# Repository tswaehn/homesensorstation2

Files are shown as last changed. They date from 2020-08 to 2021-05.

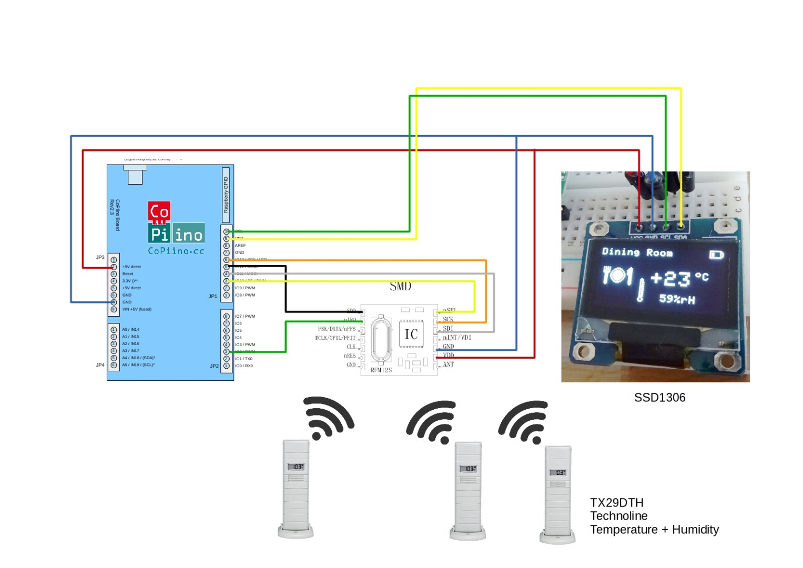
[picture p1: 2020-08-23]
dok/Home Sensor Station I - wiring.jpg

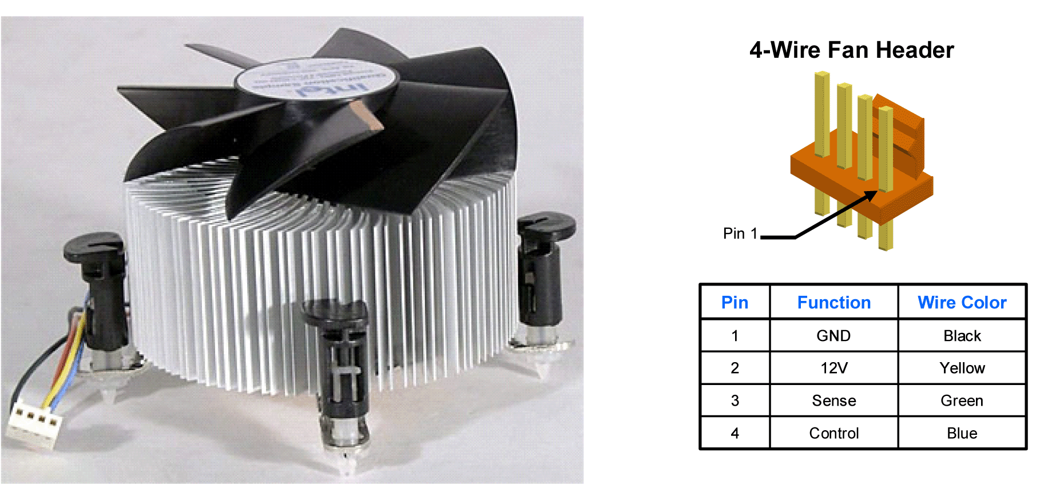
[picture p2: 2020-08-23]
dok/4pin_fan_connector_C0203-Figure1.gif

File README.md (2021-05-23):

# homesensorstation2

## requirements
*  NodeMCU Board
   * Arduino compatible ESP8266 controller board (4MB flash, I2C, SPI, WiFi, ... )
   * doc in german https://www.mikrocontroller-elektronik.de/nodemcu-esp8266-tutorial-wlan-board-arduino-ide/
*  RFM12B
   * https://www.ebay.de/itm/RFM12B-868Mhz-Wireless-Transceiver-from-HopeRF-RFM12B-868S2P-/171670876052
*  HomeSensor2 Base board
   * this board hosts the RFM12B, SSD1306 display and NodeMCU
   * schematics is in the repo 
*  SSD1306 display (128x64 pixels)
   * any compatible display with I2C will do
*  Sensors must be TX29 compatible
   * see here http://fredboboss.free.fr/articles/tx29.php
*  Arduino IDE 1.8.9
   * I personally prefer exactly this version, others may do it as well

## installation
*  install ESP8266 boards (follow instructions https://github.com/esp8266/Arduino)
*  load the arduino project
*  select "Tools" - "Board" - "NodeMCU (ESP 12E Module)" 
*  select "Tools" - "Port" 
*  run compile button in Arduino
*  upload to NodeMCU
*  done

***ATTENTION !!!!***

* use ardino IDE version 1.8.5
* use ESP library https://arduino.esp8266.com/stable/package_esp8266com_index.json
* use EPS board version 2.7.4
* use settings:
   * arduino_esp_settings.png

## pin-out
*  SSD1306 Display 
   * SDA: D2
   * SCL: D1
*  RFM12B
   * MOSI: D7
   * MISO: D6
   * SCK: D5
   * SS: D8
   * IRQ: D0

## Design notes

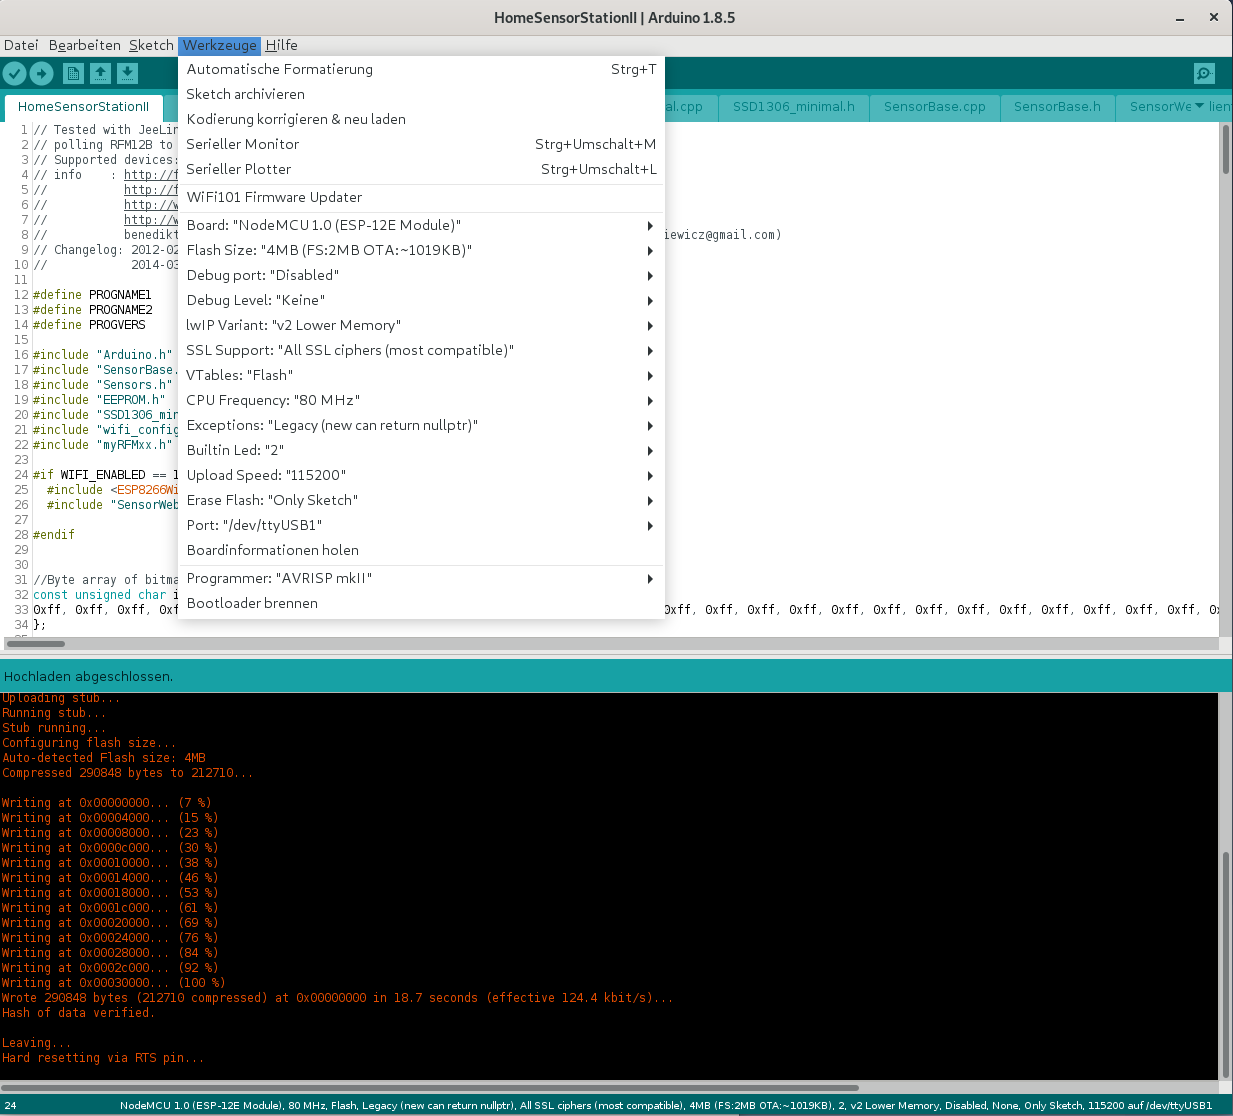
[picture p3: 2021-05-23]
arduino_esp_settings.png

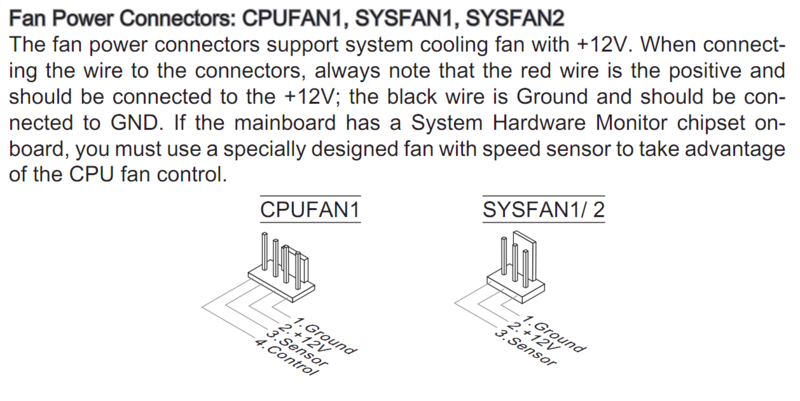
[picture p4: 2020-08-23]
dok/3pin and 4pin fan connecotr.png

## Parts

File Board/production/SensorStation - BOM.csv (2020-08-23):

Part | Value | Device | Package | Description
C1 | 100uF/10V | CPOL-EUE2.5-6 | E2,5-6 | POLARIZED CAPACITOR, European symbol
C2 | 200uF/25V | CPOL-EUE2.5-6 | E2,5-6 | POLARIZED CAPACITOR, European symbol
C3 | 100nF/10V | C-EU025-025X050 | C025-025X050 | CAPACITOR, European symbol
C4 | 100n/25V | C-EU025-025X050 | C025-025X050 | CAPACITOR, European symbol
D1 | 1N4148DO35-10 | 1N4148DO35-10 | DO35-10 | DIODE
DISP1 | DISPLAY-OLED-128X64NO-HOLES | DISPLAY-OLED-128X64NO-HOLES | DISPLAY-OLED-128X64-NO-HOLES | 128x64 Dot Matrix OLED Module
DISP2 | DISPLAY-OLED-128X32 | DISPLAY-OLED-128X32 | DISPLAY-OLED-128X32 | 128x32 Dot Matrix OLED Module with I2C interface based on SSD1306 chip
DISP3 | DISPLAY-OLED-128X64-I2CNO-HOLES | DISPLAY-OLED-128X64-I2CNO-HOLES | DISPLAY-OLED-128X64-I2C-NO-HOLES | OLED 0.96 128x64 I2C Display"
H1 | MOUNT-HOLE3.2 | MOUNT-HOLE3.2 | 3,2 | MOUNTING HOLE with drill center marker
H2 | MOUNT-HOLE3.2 | MOUNT-HOLE3.2 | 3,2 | MOUNTING HOLE with drill center marker
H3 | MOUNT-HOLE3.2 | MOUNT-HOLE3.2 | 3,2 | MOUNTING HOLE with drill center marker
H4 | MOUNT-HOLE3.2 | MOUNT-HOLE3.2 | 3,2 | MOUNTING HOLE with drill center marker
IC1 | ESP12E_DEVKITNO-HOLES | ESP12E_DEVKITNO-HOLES | ESP12E_DEVKIT-NO-HOLES | ESP12E DEVKIT BOARD
IC2 | RFM12B/69CW | RFM12B/69CW | RFM12B/69CW
IC3 | 7805TV | 7805TV | TO220V | Positive VOLTAGE REGULATOR
JP1 |  | PINHD-1X1 | 1X01 | PIN HEADER
JP2 | FAN_OUTPUT | PINHD-1X4 | 1X04 | PIN HEADER
JP3 | FAN_PWR_INPUT | PINHD-1X2 | 1X02 | PIN HEADER
JP4 |  | PINHD-1X1 | 1X01 | PIN HEADER
Q1 | IRF510 | IRF510 | TO220 | N-Channel Enhancement MOSFET (HEXFET); 100V; 5,6A; 0,54Ohm
R1 | 4k7 | R-EU_0204/5 | 0204/5 | RESISTOR, European symbol
R2 | 4k7 | R-EU_0204/5 | 0204/5 | RESISTOR, European symbol
R3 | 4k7 | R-EU_0204/5 | 0204/5 | RESISTOR, European symbol
R4 | 4k7 | R-EU_0204/5 | 0204/5 | RESISTOR, European symbol
SJ1 |  | SJ2W | SJ_2 | SMD solder JUMPER
SJ2 |  | SJ2W | SJ_2 | SMD solder JUMPER
SJ3 |  | SJ2W | SJ_2 | SMD solder JUMPER
SJ4 |  | SJ2W | SJ_2 | SMD solder JUMPER

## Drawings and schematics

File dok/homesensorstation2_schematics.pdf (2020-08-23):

## sven.ginka@gmail.com sven.ginka@gmail.com

This schematic is open source. Use only when sharing alike revisions publically.

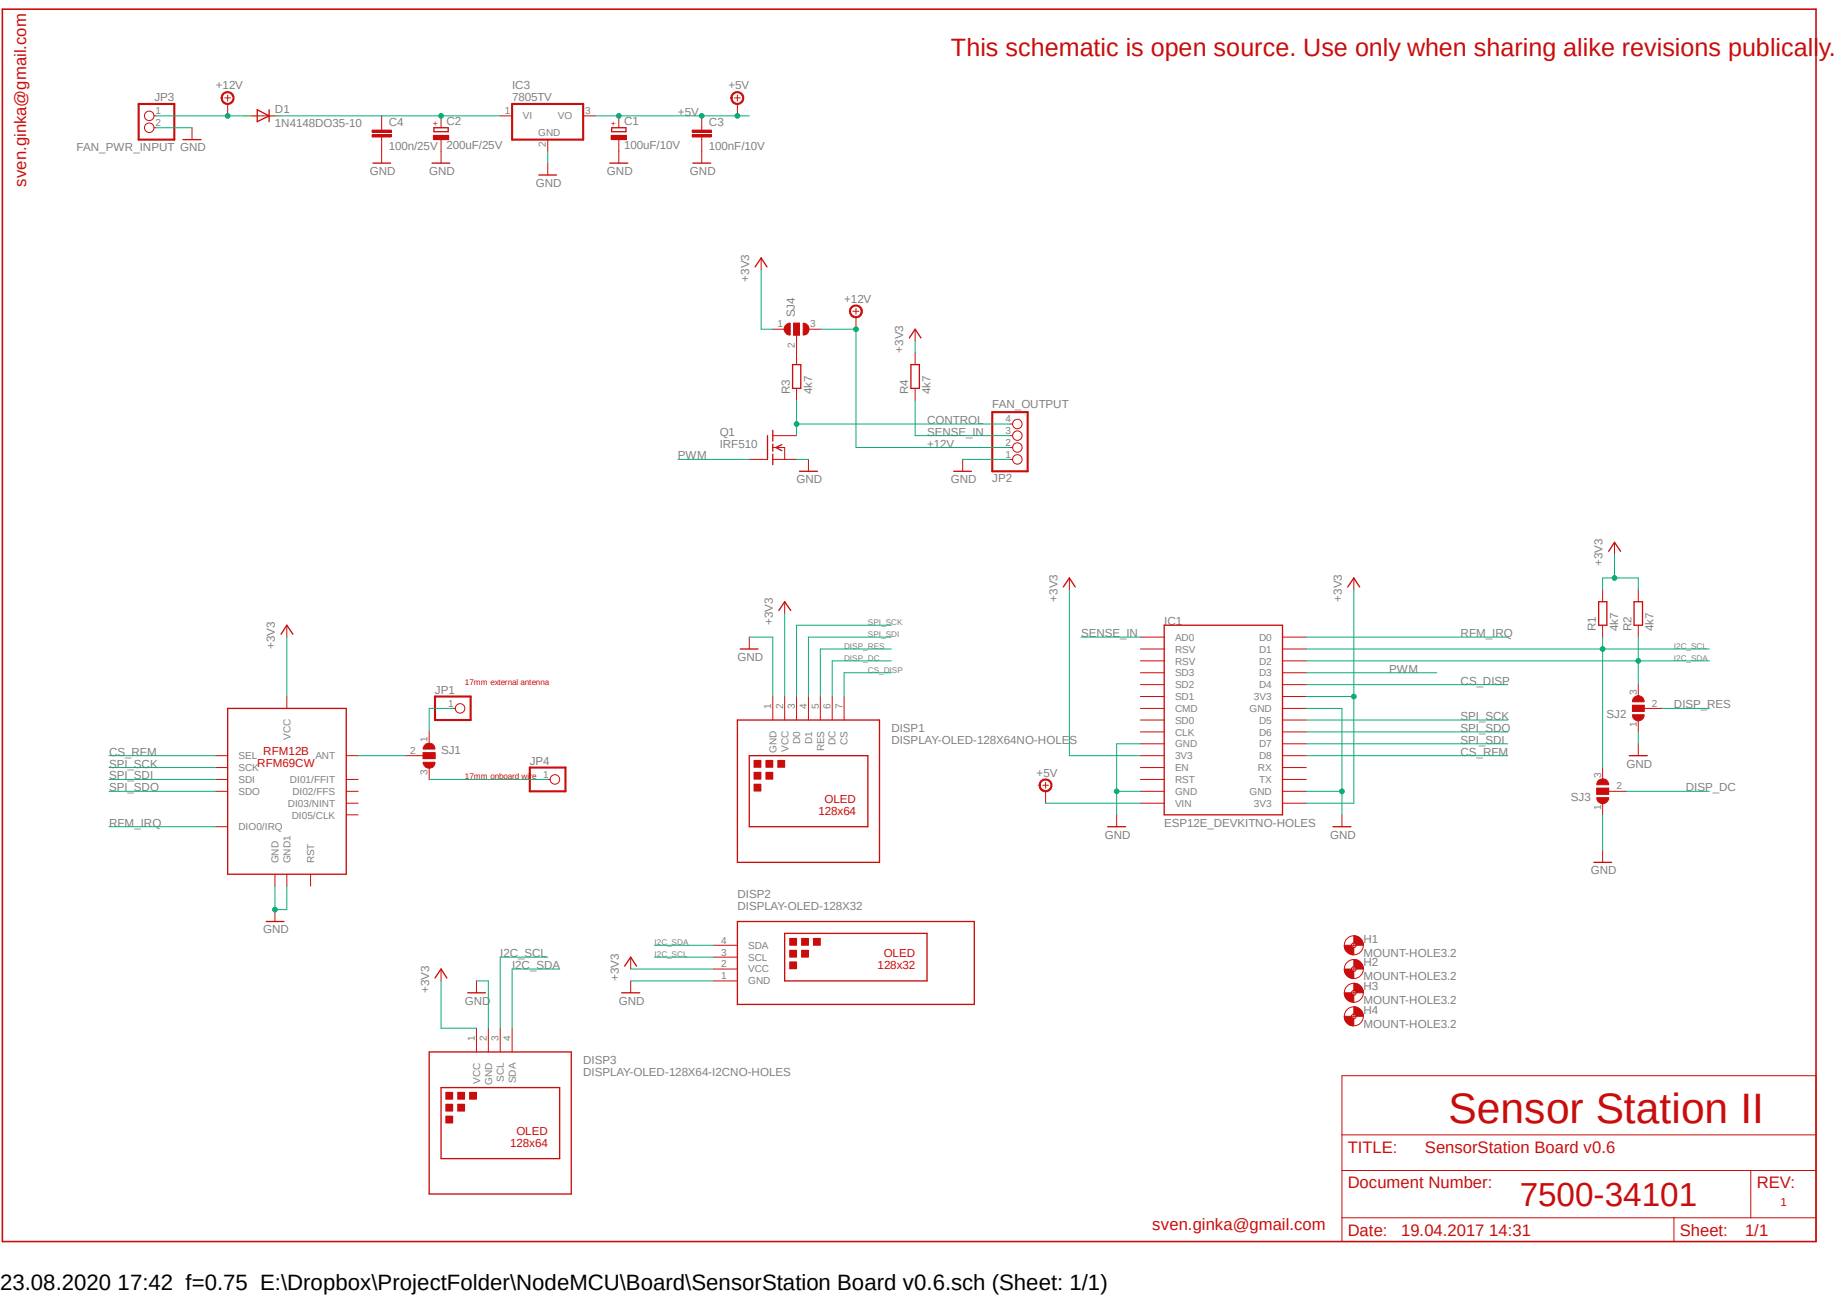
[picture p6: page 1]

DISPLAY-OLED-128X64-I2CNO-HOLES ⁺³V³

Document Number: 7500-34101 | REV: 1

Date: 19.04.2017 14:31 | Sheet: 1/1

23.08.2020 17:42 f=0.75 E:\Dropbox\ProjectFolder\NodeMCU\Board\SensorStation Board v0.6.sch (Sheet: 1/1)

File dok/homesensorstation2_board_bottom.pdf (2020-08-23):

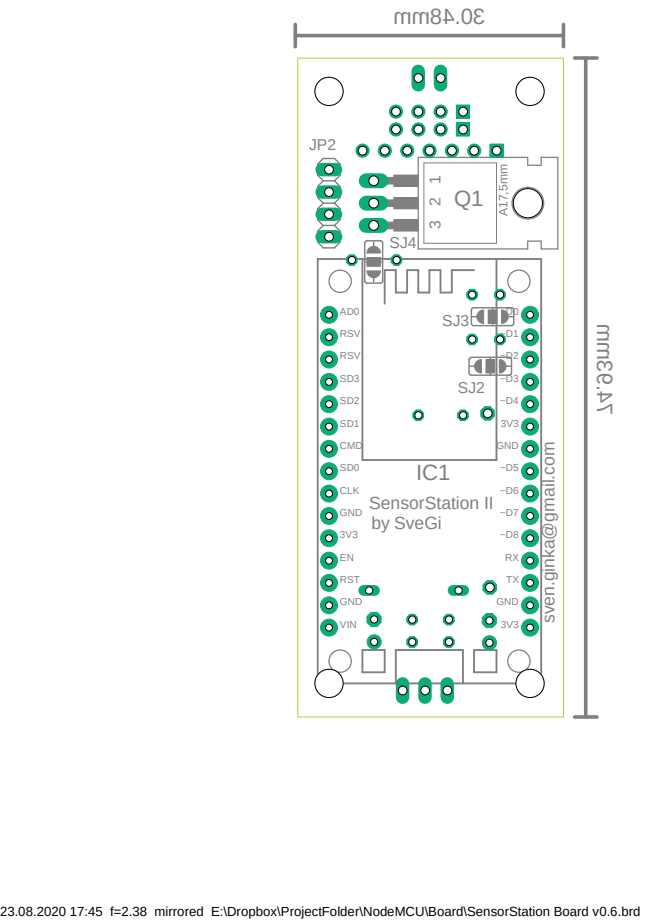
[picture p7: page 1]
RSV; CMD; CLK; GND; RST; VIN; SensorStation II; by SveGi; sven.ginka@gmail.com IC1

23.08.2020 17:45 f=2.38 mirrored E:\Dropbox\ProjectFolder\NodeMCU\Board\SensorStation Board v0.6.brd A¹⁷,5mm

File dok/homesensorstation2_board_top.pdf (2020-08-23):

- | + by CoPiino Electronics | HomeSensorStationII rev1 SJ1

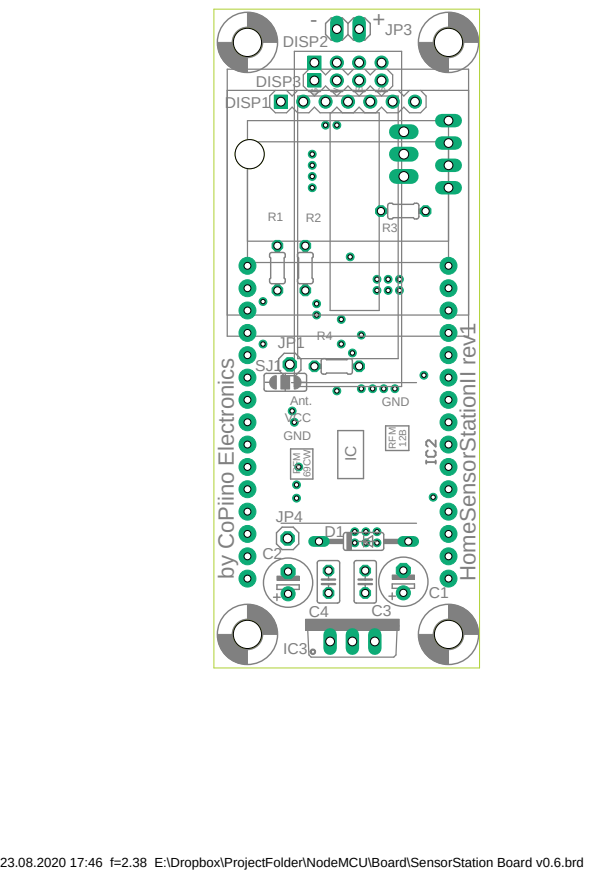
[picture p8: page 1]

23.08.2020 17:46 f=2.38 E:\Dropbox\ProjectFolder\NodeMCU\Board\SensorStation Board v0.6.brd

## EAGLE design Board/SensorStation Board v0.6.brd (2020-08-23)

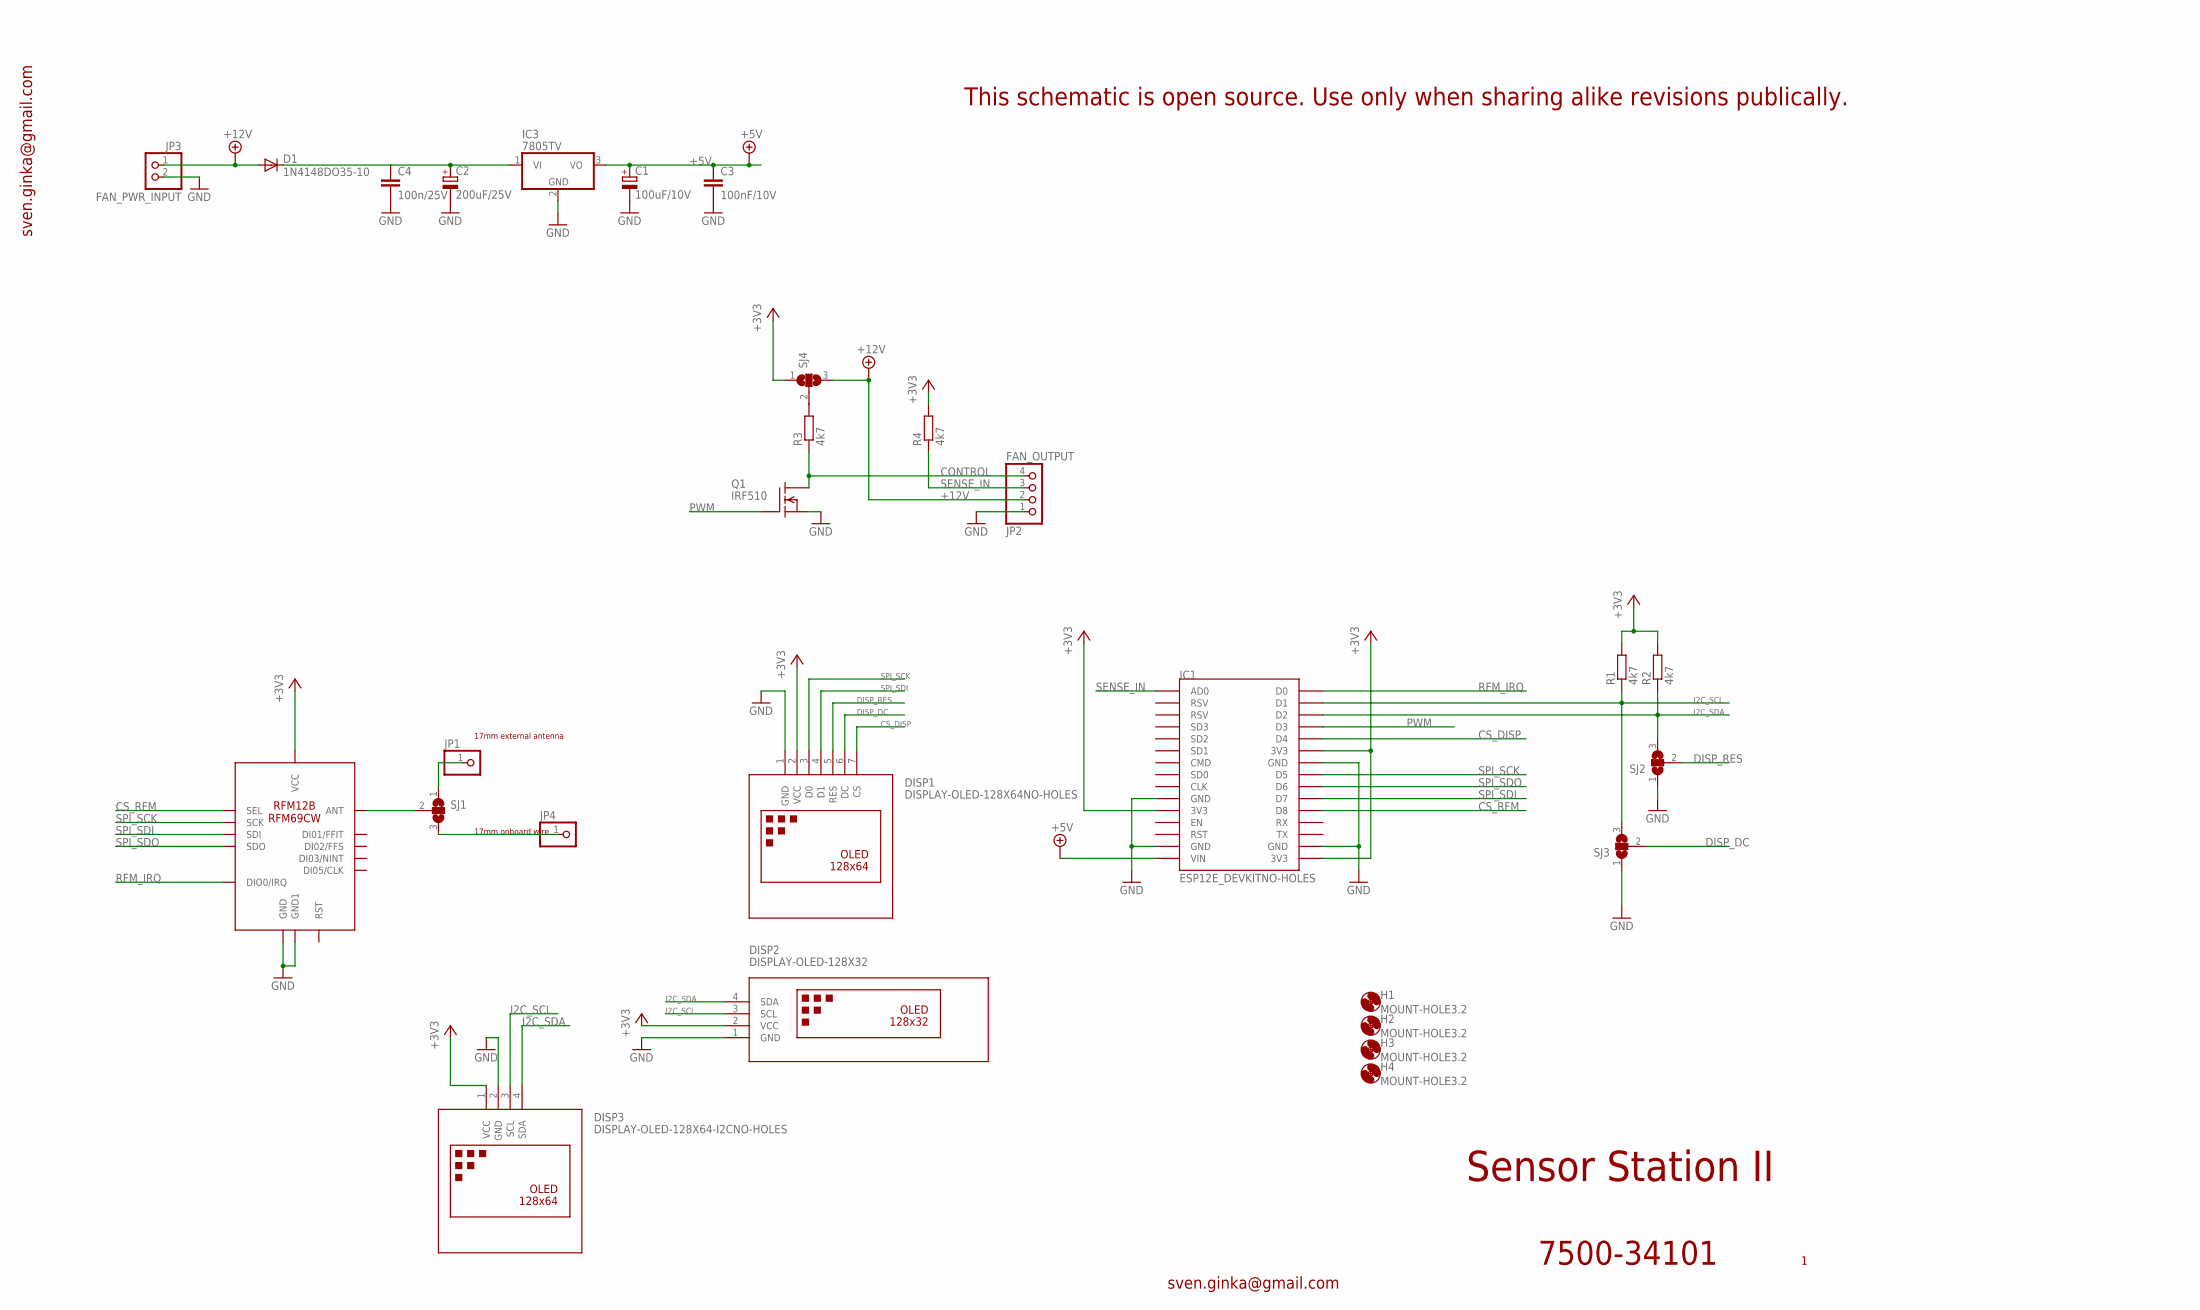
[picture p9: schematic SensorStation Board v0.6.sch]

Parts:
C1: 100uF/10V; E2,5-6
C2: 200uF/25V; E2,5-6
C3: 100nF/10V; C025-025X050
C4: 100n/25V; C025-025X050
D1: 1N4148DO35-10; DO35-10
DISP1: DISPLAY-OLED-128X64NO-HOLES; DISPLAY-OLED-128X64-NO-HOLES
DISP2: DISPLAY-OLED-128X32
DISP3: DISPLAY-OLED-128X64-I2CNO-HOLES; DISPLAY-OLED-128X64-I2C-NO-HOLES
H1, H2, H3, H4: MOUNT-HOLE3.2; 3,2
IC1: ESP12E_DEVKITNO-HOLES; ESP12E_DEVKIT-NO-HOLES
IC2: RFM12B/69CW
IC3: 7805TV; TO220V
JP1, JP4: PINHD-1X1; 1X01
JP2: FAN_OUTPUT; 1X04
JP3: FAN_PWR_INPUT; 1X02
Q1: IRF510; TO220
R1, R2, R3, R4: 4k7; 0204/5
SJ1, SJ2, SJ3, SJ4: SJ2W; SJ_2

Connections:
12V_INTERNAL: C2.+, C4.1, D1.C, IC3.1 (VI)
+3V3: DISP1.2 (VCC), DISP2.2 (VCC), DISP3.1 (VCC), IC1.3V3@0 (3V3), IC1.3V3@1 (3V3), IC1.3V3@2 (3V3), IC2.VDD (VCC), R1.2, R2.2, R4.2, SJ4.1
+5V: C1.+, C3.1, IC1.VIN, IC3.3 (VO)
+12V: D1.A, JP2.2, JP3.1, SJ4.3
ANTENNA: JP4.1, SJ1.3
CONTROL: JP2.4, Q1.2 (D), R3.1
CS_DISP: DISP1.7 (CS), IC1.D4
CS_RFM: IC1.D8, IC2.SEL
DISP_DC: DISP1.6 (DC), SJ3.2
DISP_RES: DISP1.5 (RES), SJ2.2
EXT_ANTENNA: JP1.1, SJ1.1
GND: C1.-, C2.-, C3.2, C4.2, DISP1.1 (GND), DISP2.1 (GND), DISP3.2 (GND), IC1.GND@0 (GND), IC1.GND@1 (GND), IC1.GND@2 (GND), IC1.GND@3 (GND), IC2.GND, IC2.GND1, IC3.2 (GND), JP2.1, JP3.2, Q1.3 (S), SJ2.1, SJ3.1
I2C_SCL: DISP2.3 (SCL), DISP3.3 (SCL), IC1.D1, R1.1, SJ3.3
I2C_SDA: DISP2.4 (SDA), DISP3.4 (SDA), IC1.D2, R2.1, SJ2.3
unnamed: IC2.ANT, SJ1.2
unnamed: R3.2, SJ4.2
PWM: IC1.D3, Q1.1 (G)
RFM_IRQ: IC1.D0, IC2.IRQ (DIO0/IRQ)
SENSE_IN: IC1.AD0, JP2.3, R4.1
SPI_SCK: DISP1.3 (D0), IC1.D5, IC2.SCK
SPI_SDI: DISP1.4 (D1), IC1.D7, IC2.SDI
SPI_SDO: IC1.D6, IC2.SDO

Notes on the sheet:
17mm onboard wire
17mm external antenna
Sensor Station II
sven.ginka@gmail.com
7500-34101
This schematic is open source. Use only when sharing alike revisions publically.

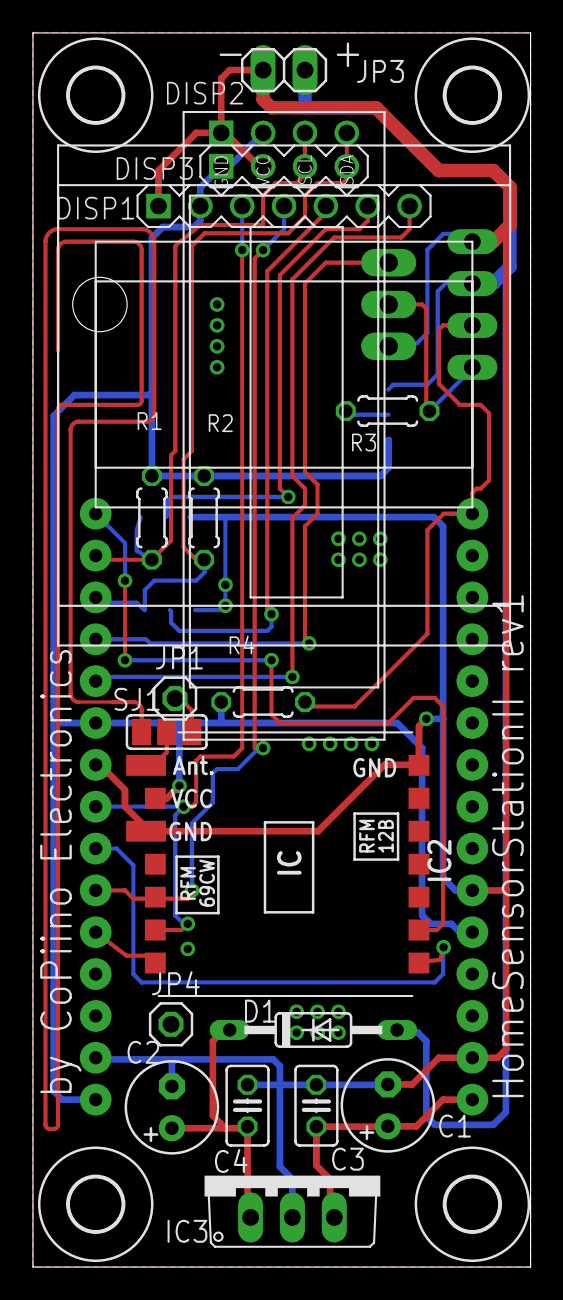
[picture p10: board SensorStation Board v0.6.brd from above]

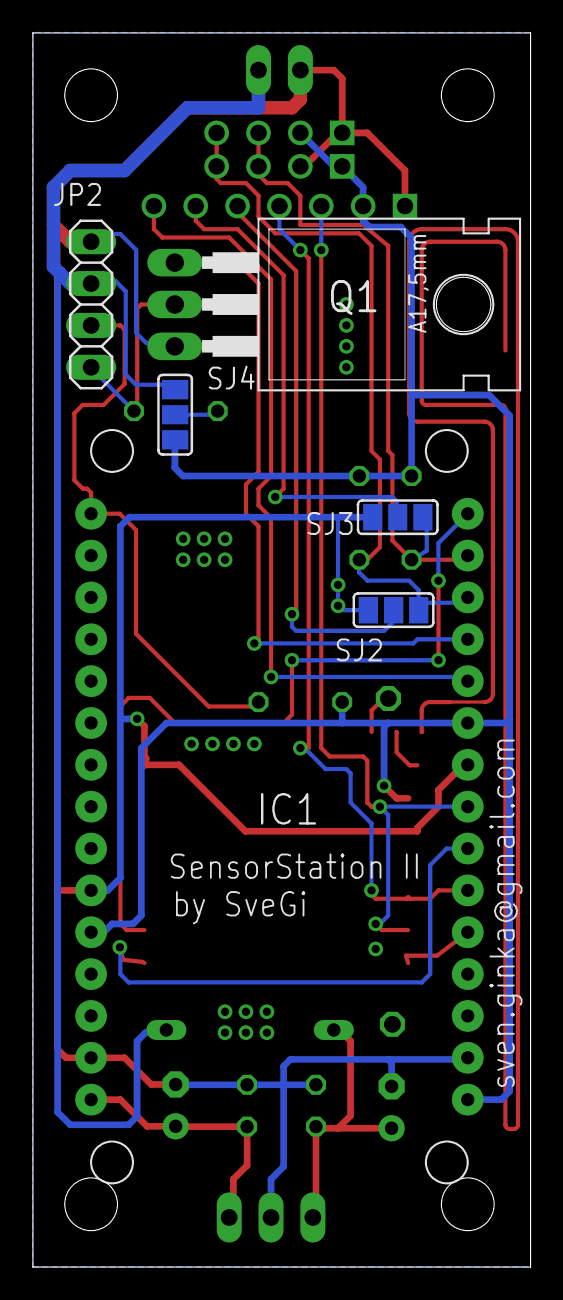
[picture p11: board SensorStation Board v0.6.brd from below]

Board: 2 copper layers, 30.2 x 74.9 mm, 28 parts (6 on the bottom side), 22 nets.

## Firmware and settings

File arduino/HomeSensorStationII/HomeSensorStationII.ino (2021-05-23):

// Tested with JeeLink v3 (2012-02-11)
// polling RFM12B to decode FSK iT+ with a JeeNode/JeeLink from Jeelabs.
// Supported devices: see FHEM wiki
// info    : http://forum.jeelabs.net/node/110
//           http://fredboboss.free.fr/tx29/tx29_sw.php
//           http://www.f6fbb.org/domo/sensors/
//           http://www.mikrocontroller.net/topic/67273 
//           benedikt.k org rinie,marf,joop 1 nov 2011, slightly modified by Rufik (r.markiewicz@gmail.com)
// Changelog: 2012-02-11: initial release 1.0
//            2014-03-14: I have this in SubVersion, so no need to do it here

#define PROGNAME1       "Home Sensor"
#define PROGNAME2       "Station"
#define PROGVERS        "v2.3" 

#include "Arduino.h"
#include "SensorBase.h"
#include "Sensors.h"
#include "EEPROM.h"
#include "SSD1306_minimal.h"
#include "wifi_config.h"
#include "myRFMxx.h"

#if WIFI_ENABLED == 1
  #include <ESP8266WiFi.h>  
  #include "SensorWebClient.h"
  
#endif


//Byte array of bitmap of 76 x 56 px:
const unsigned char img_logo [] PROGMEM = {
0xff, 0xff, 0xff, 0xff, 0xff, 0xff, 0x7f, 0x3f, 0x1f, 0x1f, 0x1f, 0x1f, 0x1f, 0x1f, 0xff, 0xff, 0xff, 0xff, 0xff, 0xff, 0xff, 0xff, 0xff, 0xff, 0xff, 0xff, 0xff, 0xff, 0xff, 0xff, 0xff, 0x00, 0x00, 0x00, 0x00, 0x00, 0x00, 0x00, 0x00, 0x00, 0x00, 0x00, 0x00, 0x00, 0x00, 0x00, 0x00, 0x00, 0x00, 0x00, 0x00, 0x00, 0x00, 0x00, 0x00, 0x00, 0x00, 0x00, 0x00, 0x00, 0x00, 0x00, 0x00, 0x00, 0x00, 0x00, 0x00, 0x00, 0x00, 0x00, 0x00, 0x00, 0x00, 0x00, 0x00, 0x00, 0xff, 0xff, 0xff, 0xff, 0x07, 0x00, 0x30, 0xfc, 0xff, 0xff, 0xff, 0xff, 0xff, 0xff, 0xff, 0xff, 0xff, 0x0f, 0x07, 0xc3, 0xe3, 0xe3, 0xe3, 0xe3, 0xc3, 0x07, 0x0f, 0xff, 0xff, 0xff, 0xff, 0x00, 0x00, 0x00, 0x00, 0x00, 0x00, 0x00, 0x00, 0x00, 0x00, 0x00, 0x00, 0x00, 0x00, 0x00, 0x00, 0x00, 0x00, 0x00, 0x00, 0x00, 0x00, 0x00, 0x00, 0x00, 0x00, 0x00, 0x00, 0x00, 0x00, 0x00, 0x00, 0x00, 0x00, 0x00, 0x00, 0x00, 0x00, 0x00, 0x00, 0x00, 0x00, 0x00, 0x00, 0x00, 0xff, 0xff, 0xff, 0xff, 0xff, 0xfc, 0xf0, 0xe1, 0xc3, 0xc7, 0xc7, 0xc7, 0xc7, 0xc7, 0xff, 0xff, 0xff, 0xf0, 0xe0, 0xe3, 0xc7, 0xc7, 0xc7, 0xc7, 0xe3, 0xe0, 0xf0, 0xff, 0xff, 0xff, 0xff, 0x00, 0x00, 0x00, 0x00, 0x00, 0x00, 0x00, 0x00, 0x00, 0x00, 0x00, 0x00, 0x00, 0x00, 0x00, 0x00, 0x00, 0x00, 0x00, 0x00, 0x00, 0x00, 0x00, 0x00, 0x00, 0x00, 0x00, 0x00, 0x00, 0x00, 0x00, 0x00, 0x00, 0x00, 0x00, 0x00, 0x00, 0x00, 0x00, 0x00, 0x00, 0x00, 0x00, 0x00, 0x00, 0xe3, 0xe3, 0xe3, 0xe3, 0xe3, 0xe3, 0x03, 0x7f, 0x7f, 0x7f, 0x7f, 0x03, 0xe3, 0x03, 0x7f, 0x7f, 0x7f, 0x03, 0xe3, 0x03, 0x7f, 0x7f, 0x7f, 0x7f, 0x03, 0xe3, 0xe3, 0xe3, 0xe3, 0xe3, 0xe3, 0x00, 0x00, 0xe0, 0xe0, 0xe0, 0xe0, 0xe0, 0xe0, 0xe0, 0xe0, 0xe0, 0xe0, 0xe0, 0xe0, 0xe0, 0xe0, 0xe0, 0xe0, 0xe0, 0xe0, 0xe0, 0xe0, 0xe0, 0xe0, 0xe0, 0xe0, 0xe0, 0xe0, 0xe0, 0xe0, 0xe0, 0xe0, 0xe0, 0xe0, 0xe0, 0xe0, 0xe0, 0xe0, 0xe0, 0xe0, 0xe0, 0xe0, 0xe0, 0xe0, 0xe0, 0xff, 0xff, 0xff, 0xff, 0xff, 0xff, 0x0f, 0x0f, 0x8f, 0x8f, 0x8f, 0x8f, 0x8f, 0x8f, 0x0f, 0x1f, 0x7f, 0xff, 0xff, 0xff, 0xff, 0x8f, 0x8f, 0x8f, 0xff, 0xff, 0xff, 0xff, 0xff, 0xff, 0xff, 0x00, 0x00, 0xff, 0xff, 0xff, 0xff, 0xff, 0xff, 0x9f, 0x8f, 0x8f, 0x8f, 0xff, 0xff, 0xff, 0xff, 0xff, 0xff, 0xff, 0xff, 0xff, 0xff, 0xff, 0xff, 0xff, 0xff, 0xff, 0xff, 0xff, 0xff, 0xff, 0xff, 0xff, 0xff, 0xff, 0xff, 0xff, 0xff, 0xff, 0xff, 0xff, 0xff, 0xff, 0xff, 0xff, 0xff, 0xff, 0xff, 0xff, 0xff, 0xff, 0x00, 0x00, 0x8f, 0x8f, 0x8f, 0x8f, 0x8f, 0x8f, 0xc0, 0xc0, 0xf0, 0xff, 0xff, 0xf9, 0xf1, 0x01, 0x01, 0x01, 0xff, 0xff, 0xff, 0xff, 0xff, 0xff, 0xff, 0x00, 0x00, 0xff, 0xff, 0xff, 0xff, 0xff, 0xf9, 0xf1, 0x01, 0x01, 0x01, 0xff, 0xff, 0xff, 0xff, 0xff, 0x01, 0x01, 0x03, 0xe3, 0xf1, 0xf1, 0xf1, 0xf1, 0x01, 0x03, 0xff, 0xff, 0xff, 0xff, 0x07, 0x03, 0xe1, 0xf1, 0xf1, 0xf1, 0xf1, 0xe1, 0x03, 0x07, 0xff, 0xff, 0xff, 0xff, 0xff, 0xff, 0xff, 0xff, 0xff, 0xff, 0xe0, 0xe0, 0xff, 0xff, 0xff, 0xff, 0xff, 0xff, 0xff, 0xff, 0xff, 0xff, 0xff, 0xe3, 0xe3, 0xe0, 0xe0, 0xe0, 0xe3, 0xe3, 0xf7, 0xff, 0xff, 0xff, 0xff, 0x00, 0x00, 0xff, 0xff, 0xff, 0xff, 0xff, 0xe3, 0xe3, 0xe0, 0xe0, 0xe0, 0xe3, 0xe3, 0xf7, 0xff, 0xff, 0xf0, 0xe0, 0xf0, 0xff, 0xff, 0xff, 0xff, 0xff, 0xf0, 0xe0, 0xff, 0xff, 0xff, 0xff, 0xf8, 0xf0, 0xf1, 0xe3, 0xe3, 0xe3, 0xe3, 0xf1, 0xf0, 0xf8, 0xff, 0xff, 0xff, 0xff
};

//byte array of bitmap 5x24px
const unsigned char  img_thermometer[] PROGMEM = {
  
  0x00, 0xfe, 0x03, 0xfe, 0x50,
  0x00, 0xff, 0x00, 0xff, 0x55,
  0x60, 0x9f, 0x80, 0x9f, 0x65,
   
};

// byte array of bitmap 32x32 => 32 x 4
const unsigned char img_fridge[] PROGMEM = {
    0x00, 0x00, 0x80, 0xa0, 0xe0, 0xc0, 0xf0, 0x00, 0x00, 0xc0, 0x00, 0x40, 0x42, 0x84, 0x88, 0xff, 0xff, 0x88, 0x84, 0x42, 0x40, 0x00, 0xc0, 0x00, 0x00, 0xf0, 0xc0, 0xe0, 0xa0, 0x80, 0x00, 0x00, 0x00, 0x00, 0x00, 0x00, 0x00, 0x08, 0x09, 0x0b, 0x0e, 0x0f, 0x18, 0x30, 0x60, 0xc4, 0x88, 0x7f, 0x7f, 0x88, 0xc4, 0x60, 0x30, 0x18, 0x0f, 0x0e, 0x0b, 0x09, 0x08, 0x00, 0x00, 0x00, 0x00, 0x00, 0x00, 0x00, 0x00, 0x00, 0x00, 0x10, 0x90, 0xd0, 0x70, 0xf0, 0x18, 0x0c, 0x06, 0x23, 0x11, 0xfe, 0xfe, 0x11, 0x23, 0x06, 0x0c, 0x18, 0xf0, 0x70, 0xd0, 0x90, 0x10, 0x00, 0x00, 0x00, 0x00, 0x00, 0x00, 0x00, 0x01, 0x05, 0x07, 0x03, 0x0f, 0x00, 0x00, 0x03, 0x00, 0x02, 0x42, 0x21, 0x11, 0xff, 0xff, 0x11, 0x21, 0x42, 0x02, 0x00, 0x03, 0x00, 0x00, 0x0f, 0x03, 0x07, 0x05, 0x01, 0x00, 0x00
};

// byte array of bitmap 32x32 => 32 x 4
const unsigned char img_weather[] PROGMEM = {
    0x00, 0x00, 0x00, 0x00, 0x00, 0x00, 0x00, 0x10, 0x30, 0x60, 0xc0, 0x80, 0x06, 0x0c, 0x38, 0xa0, 0x80, 0xc0, 0xc0, 0xd0, 0xde, 0x83, 0x80, 0x00, 0x60, 0x30, 0x18, 0x0c, 0x06, 0x00, 0x80, 0x80, 0x00, 0x00, 0x00, 0x00, 0x00, 0x00, 0xe0, 0xe0, 0x00, 0x80, 0xc0, 0xe1, 0xcc, 0x9e, 0x3f, 0x7f, 0xff, 0xff, 0xff, 0xff, 0xff, 0xff, 0xff, 0xff, 0xfe, 0xfc, 0xf0, 0x06, 0x82, 0xc3, 0x41, 0x40, 0x00, 0x80, 0xc0, 0x60, 0xf0, 0xf8, 0xff, 0xff, 0xff, 0xff, 0xff, 0xff, 0xff, 0xff, 0xff, 0xfe, 0xfc, 0xf9, 0xf3, 0x67, 0xcf, 0x9f, 0x1f, 0x0f, 0x27, 0x63, 0xc0, 0x84, 0x0c, 0x0c, 0x18, 0x18, 0x01, 0x01, 0x00, 0x00, 0xff, 0xff, 0xff, 0xff, 0xff, 0xff, 0xff, 0xff, 0x01, 0x01, 0x01, 0xff, 0xff, 0xff, 0xff, 0x00, 0x00, 0x01, 0x01, 0x00, 0x00, 0x00, 0x00, 0x01, 0x01, 0x00, 0x00, 0x00
};

// byte array of bitmap 32x32 => 32 x 4
const unsigned char img_dining[] PROGMEM = {
    0xe0, 0x00, 0xe0, 0x00, 0xe0, 0x00, 0xe0, 0x00, 0x00, 0x00, 0x00, 0x00, 0x80, 0x80, 0x40, 0x40, 0x40, 0x40, 0x80, 0x80, 0x00, 0x00, 0x00, 0x00, 0x00, 0x00, 0x00, 0x80, 0xc0, 0xe0, 0xc0, 0x00, 0x07, 0x0c, 0xff, 0xf8, 0xff, 0x0c, 0x07, 0x00, 0xf0, 0x0c, 0x62, 0xf9, 0xfc, 0xfe, 0xfe, 0xff, 0xff, 0xfe, 0xfe, 0xfc, 0xf9, 0x62, 0x0c, 0xf0, 0x00, 0x00, 0x1f, 0x3f, 0xff, 0xff, 0xff, 0x00, 0x00, 0x00, 0x7f, 0xff, 0x7f, 0x00, 0x00, 0x00, 0x00, 0x03, 0x04, 0x09, 0x13, 0x17, 0x27, 0x2f, 0x2f, 0x27, 0x17, 0x13, 0x09, 0x04, 0x03, 0x00, 0x00, 0x00, 0x00, 0x00, 0x7f, 0xff, 0x7f, 0x00, 0x00, 0x00, 0x00, 0x00, 0x00, 0x00, 0x00, 0x00, 0x00, 0x00, 0x00, 0x00, 0x00, 0x00, 0x00, 0x00, 0x00, 0x00, 0x00, 0x00, 0x00, 0x00, 0x00, 0x00, 0x00, 0x00, 0x00, 0x00, 0x00, 0x00, 0x00, 0x00
};

// byte array of bitmap 13x8 => 13 x 1
const unsigned char img_battery_low[] PROGMEM = {
    0xff, 0x81, 0xbd, 0xbd, 0x81, 0x81, 0x81, 0x81, 0x81, 0x81, 0xff, 0x42, 0x3c
};

// byte array of bitmap 13x8 => 13 x 1
const unsigned char img_battery_full[] PROGMEM = {
    0xff, 0x81, 0xbd, 0xbd, 0xbd, 0xbd, 0xbd, 0xbd, 0xbd, 0x81, 0xff, 0x42, 0x3c
};





SSD1306_Mini oled;
// mosi, miso, sck, ss, irq 
//RFMxx rfm1(D7, D6, D5, D8, D0);
MyRFMxx myRFMxx(D7, D6, D5, D8, D0, true);




void splash(){

  oled.startScreen();
  oled.clear();
  
  oled.drawImage( img_logo, 20,0, 76, 7 );
  oled.cursorTo(0,7);
  oled.printString( "http://CoPiino.cc");
  
  delay(4000);

  oled.clear();
  oled.cursorTo(26, 3);
  oled.printString( PROGNAME1 );
  oled.cursorTo(40, 4);
  oled.printString( PROGNAME2 );
  oled.cursorTo(50, 5);
  oled.printString( PROGVERS );

  delay(4000);
  
  oled.clear();
  oled.startScreen();

}

void display(){

  char buf[50];
  #define DEG "\xa7" "C"
  
  static unsigned long startTime= 0;
  unsigned long currentTime= millis();
  
  if ((currentTime-startTime) < 4000){
        return; 
  }
  startTime= currentTime;
  
  
  
  oled.drawImage( img_thermometer, 45,4, 5, 3 );

  
  static char sensorNr= 0;
  
  Sensors::sSensor * pSensor= sensors.getSensor(sensorNr);
  //
  if (pSensor==0){
    return;
  }

  // draw battery symbol
  if (pSensor->batteryLow){
      oled.drawImage( img_battery_low, 114,0, 13, 1 );
  } else {
      oled.drawImage( img_battery_full, 114,0, 13, 1 );
  }

  // update temperature
  signed char temperature= (signed char) pSensor->temperature;
  dtostrf( temperature, 3, 0, buf );
  //sprintf(buf, "%+0.2d" , temperature);

  // print to display
  oled.printString2( 55, 3, buf );
  // set cursor
  oled.cursorTo(100, 3);
  oled.printString( DEG );

  
  // update humidity
  unsigned char humidity= (unsigned char) pSensor->humidity;
  itoa( humidity, buf, 10 );
  //sprintf(buf, "%0.2d%%rH", humidity);
  // set cursor
  oled.cursorTo(67, 6);
  // print to display
  oled.printString( buf );
  oled.printString( " %rH" );

  // update name
  oled.cursorTo(0, 0);
  oled.printString( pSensor->name );
  
  switch(sensorNr){
        
    case 0: oled.drawImage( img_fridge, 5,2, 32, 4 ); break;
    case 1: oled.drawImage( img_weather, 5,2, 32, 4 ); break;
    case 2: oled.drawImage( img_dining, 5,2, 32, 4 ); break;
    
    default:
          oled.drawImage( img_fridge, 10,2, 32, 4 );
    
  }

  // write error counter
  unsigned char errors= pSensor->errors;
  itoa( errors, buf, 10 );
  oled.cursorTo(0,7);
  oled.printString( buf );

    
  sensorNr++;
  if (sensorNr>=3){
        sensorNr=0;
  }

}


// **********************************************************************
void loop(void) {
  // Handle the commands from the serial port
  // ----------------------------------------
  if (Serial.available()) {
    //HandleSerialPort(Serial.read());
  }


  struct MyRFMxx::Frame frame;
  myRFMxx.process(frame);
  if (frame.IsValid){
    Serial.print(" ID:");
    Serial.print(frame.ID);
    Serial.print(" Temp:");
    Serial.print(frame.Temperature);
    Serial.print(" Hum:");
    Serial.print(frame.Humidity);
    Serial.println();

    Sensors::HandleSensorData( frame.ID, frame.Temperature, frame.Humidity, frame.WeakBatteryFlag );
  }
  
  //
  //
  sensors.process();
  
  //
  //
  display();
  
  static unsigned long lastTime= 0;
  unsigned long currentTime= millis();

  // upload every 10min to Internet
  /*
  if ((currentTime-lastTime) > (1000*60)){
    lastTime= currentTime;
    Sensors::sSensor * pSens;
    

    // sensor of fridge
    //Sensors::sSensor * pSens= sensors.getSensor( 0 );
    //sensorWebClient.send("8812ea0f0a57150e73596892218692c0", pSens->humidity );
    //sensorWebClient.send("80e3a73b12ca1951dde6ac1d421ee165", pSens->temperature );

    // sensor of weather
    pSens= sensors.getSensor( 1 );
    sensorWebClient.send("fa1299d150f525759ae8265cbe781362", pSens->humidity );
    sensorWebClient.send("c981a2c66d5e6757155e45726eda805d", pSens->temperature );

    // sensor of dining room
    pSens= sensors.getSensor( 2 );
    sensorWebClient.send("8812ea0f0a57150e73596892218692c0", pSens->humidity );
    sensorWebClient.send("80e3a73b12ca1951dde6ac1d421ee165", pSens->temperature );
    
  }
  */
  
}


void setup(void) {

  Serial.begin(115200);
  delay(200);
    Serial.println();
    Serial.println();
    Serial.println("*** LaCrosse weather station wireless receiver for IT+ sensors ***");

  
  // OLED
  oled.init(0x3c);
  oled.clear();

  delay(1000);
  
  splash();

  #if WIFI_ENABLED == 1
    // call the setup for wifi
    char * ssid= WIFI_SSID;
    char * password= WIFI_PSK;
    sensorWebClient.setup(ssid, password);
  
  #endif
    
  
  //
  
  sensors.addSensor( 0, "Fridge     ", 20 );//53
  sensors.addSensor( 1, "Weather    ", 30 );//4
  sensors.addSensor( 2, "Dining Room", 24 );//42

  myRFMxx.setup();
  
  Serial.println("setup complete");

}





 

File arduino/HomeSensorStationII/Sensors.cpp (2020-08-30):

#include "Sensors.h" 
#include "EEPROM.h"

Sensors sensors;

Sensors::Sensors(){

  // load IDs from EEPROM
  loadNeeded= 1;
  
  for (char idx=0;idx<SENS_COUNT;idx++){
    s[idx].rxID= 0;
    s[idx].temperature= 0.0;
    s[idx].humidity= 0;
    s[idx].gracetime= 0;
    s[idx].batteryLow= 0;
    s[idx].updated= 0;
    s[idx].isValid= 0;     
    s[idx].errors= 0;
  }

  for (char idx=0;idx<SENS_COUNT;idx++){
    newSensIDs[idx]= 0;
  }
  newSensCount= 0;

}

void Sensors::addSensor( char idx, char Name[], char rxID ){
        
  if (idx >= SENS_COUNT){
    return;
  }
  if (idx < 0){
    return;
  }
  
  for (char i=0;i<20;i++){
        s[idx].name[i]= Name[i]; 
  }
  
  s[idx].rxID= rxID;
  s[idx].isValid= 1;
  
  
}

Sensors::sSensor * Sensors::getSensor( char idx ){
  
  if (idx >= SENS_COUNT){
    return 0;
  }
  if (idx < 0){
    return 0;
  }
  
  return &(s[idx]);
}

char Sensors::loadFromEEPROM(){

  unsigned char IDs[SENS_COUNT];
  unsigned char crc= 0;
  unsigned char crc_read= 0;
  unsigned char b;
  
  EEPROM.begin(SENS_COUNT+1);

  // load data from EEPROM
  for (char idx=0; idx<SENS_COUNT; idx++) {
      b= EEPROM.read(idx);
      IDs[idx]= b;
      crc+= b;

      Serial.print("Sens");
      Serial.print(idx, DEC);
      Serial.print(">");
      Serial.println(b, DEC);
  }   
  crc_read= EEPROM.read(SENS_COUNT);

  // check CRC
  if (crc != crc_read){
    Serial.print("CRC>");
    Serial.println( crc, DEC );
    Serial.println("CRC Failed");
    return 0;
  } else {
    Serial.println("CRC OK");    
  }

  // transfer IDs to sensor objects
  for (char idx=0; idx<SENS_COUNT; idx++) {
    s[idx].rxID= IDs[idx];  
  }
  
  Serial.println("Loaded IDs from EEPROM");

  return 1;
}

void Sensors::storeToEEPROM(){
  
  unsigned char crc= 0;
  unsigned char b;

  EEPROM.begin(SENS_COUNT+1);
  
  for (char idx=0; idx<SENS_COUNT; idx++) {
    b= s[idx].rxID;
    EEPROM.write(idx, b);
    crc +=b;
    
    Serial.print("Sens");
    Serial.print(idx, DEC);
    Serial.print(">");
    Serial.println(b, DEC);
    
  }     
  
  // write CRC
  EEPROM.write( SENS_COUNT, crc );
  EEPROM.commit();
  
  Serial.print("CRC>");
  Serial.println( crc, DEC );
  
  Serial.println("Stored IDs to EEPROM");  
  
}

void Sensors::clearEEPROM(){

  unsigned char crc= 0;
  unsigned char b;
  
  EEPROM.begin(SENS_COUNT+1);
  
  for (char idx=0; idx<SENS_COUNT; idx++) {
    b= idx;
    EEPROM.write(idx, b);
    crc +=b;  
    
    Serial.print("Sens");
    Serial.print(idx, DEC);
    Serial.print(">");
    Serial.println(b, DEC);
    
  }     
  
  // write invalid CRC
  EEPROM.write( SENS_COUNT, crc+1 );
  EEPROM.commit();

  Serial.println("Cleared IDs from EEPROM");
}


// re-organization
void Sensors::reorg(){

  unsigned char missingSens= 0;
  unsigned char missingSensIdx= 0;
  
  // check the number of missing sensors
  for (int idx= 0; idx < SENS_COUNT; idx++){
    if (s[idx].isValid){
      if (s[idx].errors > 0){
        missingSens++;       
        missingSensIdx= idx;
      }
    }
  }

  // if - and only if only 1 sensor is missing and exactly 1 new sensor exists, then we replace the ID
  if (missingSens != 1){
    Serial.println("Too many sensors missing - cannot replace");
    return;
  }
  if (newSensCount != 1){
    Serial.println("Too many new sensor - cannot find suiting matches");
    return;
  }

  // now replace
  Serial.print("Replacing ID ");
  Serial.print( s[missingSensIdx].rxID, DEC );
  Serial.print(" by ");
  Serial.println( newSensIDs[0], DEC );
    
  s[missingSensIdx].rxID= newSensIDs[0];
  storeToEEPROM();
  
  Serial.println("done");
  
}

void Sensors::process(){
        
  static unsigned long startTime= 0;
  unsigned long currentTime= millis();

/*
  // check if sensors need setup
  if (loadNeeded){
    loadNeeded= 0; // run this routine only once
      
    // for testing only
    //clearEEPROM();
    //storeToEEPROM();
    
    // try to load IDs from EEPROM
    if ( loadFromEEPROM() == 0){
      // if failed use IDs from FLASH
      storeToEEPROM();
    }
  }
*/       
  // check if 1min has passed
  if ((currentTime-startTime) > 60000){
    startTime= currentTime;
 
    // check all sensors if they were updated correctly
    for (char idx=0;idx<SENS_COUNT;idx++){
      if (s[idx].isValid==0){
        continue;
      }
      
        // sensor was not updated correctly
      if (s[idx].updated==0){
        // reset gracetime
        s[idx].gracetime= 0;
        // increase error count
        if (s[idx].errors <= 99){
          s[idx].errors++;
        }
        
        
      } else {
        // sensor was updated correctly  
        s[idx].gracetime++;
        
        // clear one error every 24hours 
        if (s[idx].gracetime >= 1440 ){ //[24hours]
          s[idx].gracetime= 0;
          // so we can check once a day for errors
          if (s[idx].errors > 0){
                s[idx].errors--; 
          }
        }
      }
      
      // reset update
      s[idx].updated= 0;
    }

    // if new sensors are attached
    if (newSensCount > 0){
      reorg();
                  
      Serial.print("New sensor count is ");
      Serial.println( newSensCount, DEC );
    }
        
    print();
  }
  
}


void Sensors::HandleSensorData( char ID, float temperature, char humidity, char batteryLow ){

  unsigned char i;
  for (i=0;i<SENS_COUNT;i++){
    if (sensors.s[i].rxID == ID ){
      sensors.s[i].temperature= temperature;
      sensors.s[i].humidity= humidity;
      sensors.s[i].batteryLow= batteryLow;
      sensors.s[i].updated= 1;
      
      return;
    }
  }

  // if we came to here then we found a new sensor
  for (i= 0; i<sensors.newSensCount; i++){
    // this new ID is already known 
    if (sensors.newSensIDs[i] == ID ){
      return;
    } 
  }

  // the new ID is unknown -- add the sensors ID
  if (sensors.newSensCount < SENS_COUNT){
    sensors.newSensIDs[sensors.newSensCount++]= ID;
    
    Serial.print("New sensor found with ID ");
    Serial.println( ID, DEC );
  }
  
}

void Sensors::print(){

  Serial.println("---");
  for (char i=0;i<SENS_COUNT;i++){
    if (s[i].isValid){
        Serial.print( s[i].name );
      Serial.print( " " );
      Serial.print( s[i].temperature );
      Serial.print( " " );
      Serial.print( s[i].humidity, DEC );
      Serial.print( " " );
      Serial.print( s[i].batteryLow, DEC );
      Serial.print( " " );
      Serial.print( s[i].errors, DEC );
      Serial.println();
      
    }
  }  
  
}

 

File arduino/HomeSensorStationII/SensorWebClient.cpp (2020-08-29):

/*
 *  This sketch sends data via HTTP GET requests to data.sparkfun.com service.
 *
 *  You need to get streamId and privateKey at data.sparkfun.com and paste them
 *  below. Or just customize this script to talk to other HTTP servers.
 *
 */
#include "SensorWebClient.h"


//const char* host = 
//const char* token   = "8812ea0f0a57150e73596892218692c0";

SensorWebClient sensorWebClient;

SensorWebClient::SensorWebClient(){
  
}


void SensorWebClient::setup(char * _ssid, char * _password) {

  // store connection details locally
  ssid= _ssid;
  password= _password;
  host= (char*) "iot.copiino.cc";
  
  // We start by connecting to a WiFi network
  
  Serial.println();
  Serial.println();
  Serial.print("Connecting to ");
  Serial.println(ssid);
  
  WiFi.begin(ssid, password);
  
  while (WiFi.status() != WL_CONNECTED) {
    delay(500);
    Serial.print(".");
    
  }

  Serial.println("");
  Serial.println("WiFi connected");  
  Serial.println("IP address: ");
  Serial.println(WiFi.localIP());

  
}


void SensorWebClient::send( char * token, int sensorValue ) {

  Serial.print("connecting to ");
  Serial.println(host);
  
  // Use WiFiClient class to create TCP connections

  const int httpPort = 80;
  if (!client.connect(host, httpPort)) {
    Serial.println("connection failed");
    return;
  }
  
  // We now create a URI for the request
  String url = "/update.php";
  url += "?token=";
  url += token;
  url += "&sensorValue=";
  url += sensorValue;
  
  Serial.print("Requesting URL: ");
  Serial.println(url);
  
  // This will send the request to the server
  client.print(String("GET ") + url + " HTTP/1.1\r\n" +
               "Host: " + host + "\r\n" + 
               "User-Agent: ESP8266" + "\r\n" +
               "Connection: close\r\n\r\n");
  delay(10);
  
  // Read all the lines of the reply from server and print them to Serial
  while(client.available()){
    String line = client.readStringUntil('\r');
    Serial.print(line);
  }
  
  Serial.println();
  Serial.println("closing connection");
}

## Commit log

2020-08-23 mod: insert dok + lbr
2020-08-23 add: production data
    [HomeSensorStationII.GBL, HomeSensorStationII.GBO, HomeSensorStationII.GBS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]
2020-08-23 add: BOM
    [SensorStation - BOM.csv]
2020-08-29 add: arduino sources
2021-05-23 fix: startup + sensors IDs + warning notes on arduino IDE version + esp-board version
    [HomeSensorStationII.ino, RFMxx.cpp, myRFMxx.cpp]

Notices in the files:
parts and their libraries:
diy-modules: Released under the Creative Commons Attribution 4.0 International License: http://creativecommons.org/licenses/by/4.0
